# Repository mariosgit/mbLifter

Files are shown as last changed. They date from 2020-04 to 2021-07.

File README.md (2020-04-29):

# mb'Lifter 

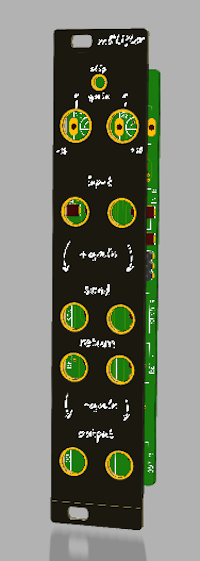
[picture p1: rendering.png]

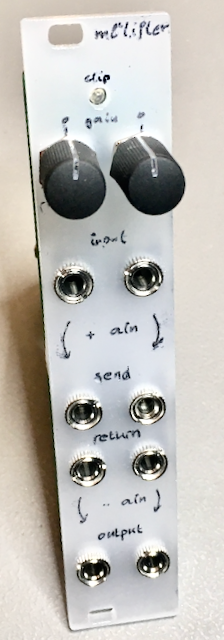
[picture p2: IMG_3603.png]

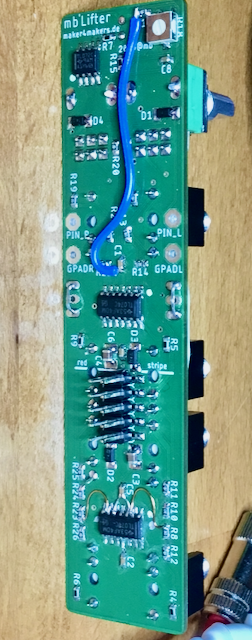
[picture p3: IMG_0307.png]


## What is it

It's a amplifier and attenuator, both coupled and controlled by one knob.

Input -> Amplify -> Attenuate -> Output

or

Input -> Attenuate -> Amplify -> Output.

the middle connection (gained or attenuated signal) can be routed anywhere.

Gain range: -18...+18 dB

It has 2 channels doing this.

Clip indicator - lights up when one of the channels opamps runs into clipping, that is signal level above +-10V peak to peak.

Other features Reverse voltage protection, requires +-12V and needs +-25mA. Width = 5HP = 25mm = almost 1".

### But Why ?

Original idea was to drive an overdrive/distortion unit, so it gains the signal, passes it to the distortion stuff, and then it attenuates to the original levels. In this way the distorted signal does not get louder only distorteder.

### Usecases

* Drive signal into distortion.

### Misuseable as

* InOut - Input an Aux signal (gain Line level to Rack level) AND Output Rack signals with Line level.
* Effect Adapter - Use Guitar effects in your rack - Attenuate to FX(line) level -> FX -> Gain back into Rack Level. Or other way around - use your rack as guitar FX unit.
* Instrument interface - cascade both channels to achive max gain of 36dB, sufficient for Mics and Guitars.
* ...

## Files in repo...

### /pcb

* Lifter01 is the beta version, left here as reference. Had a view minor bugs.
  * Missing feedback caps.
  * 2 wrongly flipped opamp gates.
* Lifter02 - current production version, labeled as "version1.0"
* FrontPCB - as name says.

## License

#### Attribution-NonCommercial-ShareAlike - CC BY-NC-SA 

```
Attribution — You must give appropriate credit, provide a link to the license, and indicate if changes were made. You may do so in any reasonable manner, but not in any way that suggests the licensor endorses you or your use.

NonCommercial — You may not use the material for commercial purposes.

ShareAlike — If you remix, transform, or build upon the material, you must distribute your contributions under the same license as the original.

No additional restrictions — You may not apply legal terms or technological measures that legally restrict others from doing anything the license permits.
```
[All the legal blabla here](https://creativecommons.org/licenses/by-nc-sa/4.0/legalcode)

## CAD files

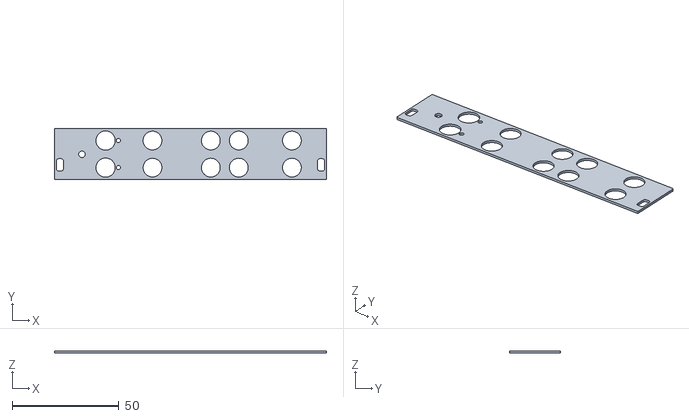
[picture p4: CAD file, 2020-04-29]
Spacer.stl
127.4 x 24.1 x 1.00

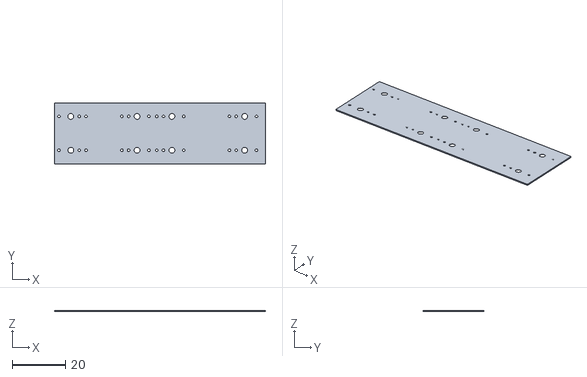
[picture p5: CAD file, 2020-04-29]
Isolator.stl
79.2 x 23.0 x 0.4

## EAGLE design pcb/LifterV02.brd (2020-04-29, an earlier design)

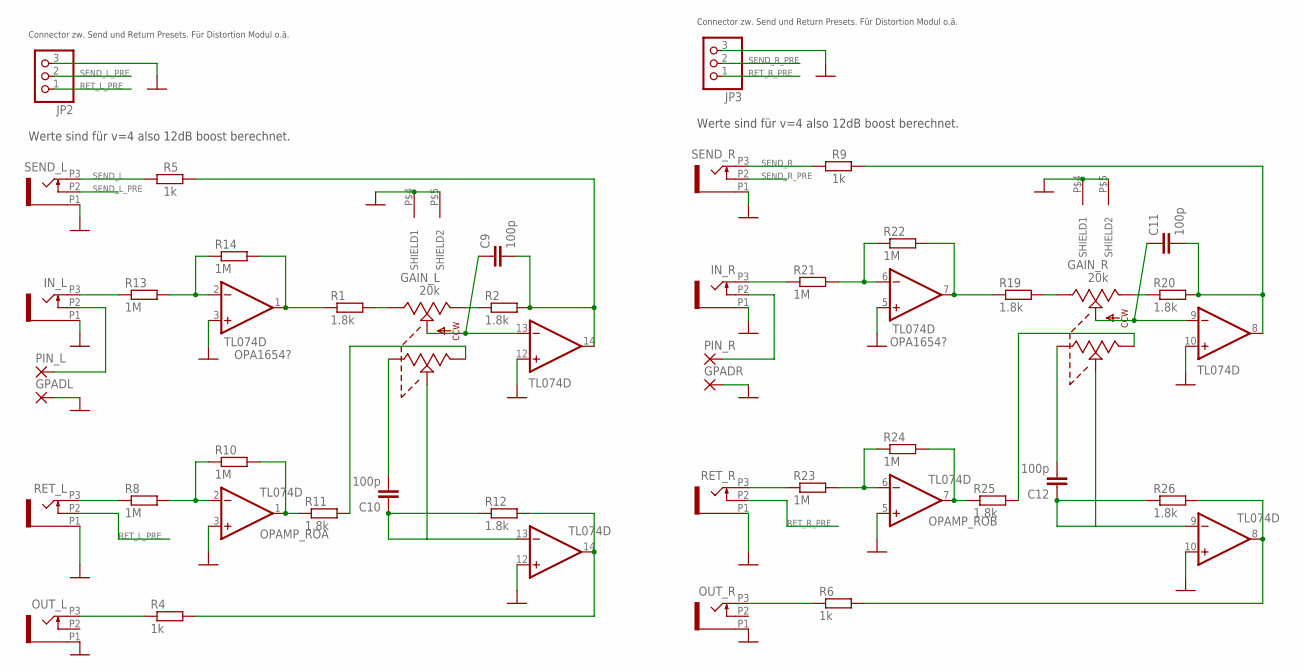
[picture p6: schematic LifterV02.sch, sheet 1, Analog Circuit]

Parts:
C9, C10, C11, C12: 100p; C0603
GAIN_L: 20k; TT_2TAP_VERTICAL
GAIN_R: 20k; TT_2TAP_VERTICAL
GPADL: 3,17/1,3
GPADR: 3,17/1,3
IN_L: PJ301_THONKICONN6; WQP_PJ_301M6
IN_R: PJ301_THONKICONN6; WQP_PJ_301M6
JP2, JP3: PINHD-1X3; 1X03
OPAMP_IS: TL074D; SO14
OPAMP_RO: TL074D; SO14
OUT_L: PJ301_THONKICONN6; WQP_PJ_301M6
OUT_R: PJ301_THONKICONN6; WQP_PJ_301M6
PIN_L: 3,17/1,3
PIN_R: 3,17/1,3
R1, R2, R11, R12, R19, R20, R25, R26: 1.8k; R0603
R4, R5, R6, R9: 1k; R0603
R8, R10, R13, R14, R21, R22, R23, R24: 1M; R0603
RET_L: PJ301_THONKICONN6; WQP_PJ_301M6
RET_R: PJ301_THONKICONN6; WQP_PJ_301M6
SEND_L: PJ301_THONKICONN6; WQP_PJ_301M6
SEND_R: PJ301_THONKICONN6; WQP_PJ_301M6

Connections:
GND: GAIN_L.P$4 (SHIELD1), GAIN_L.P$5 (SHIELD2), GAIN_R.P$4 (SHIELD1), GAIN_R.P$5 (SHIELD2), GPADL.1, GPADR.1, IN_L.P1 (1), IN_R.P1 (1), JP2.3, JP3.3, OPAMP_IS.3 (+IN), OPAMP_IS.5 (+IN), OPAMP_IS.10 (+IN), OPAMP_IS.12 (+IN), OPAMP_RO.3 (+IN), OPAMP_RO.5 (+IN), OPAMP_RO.10 (+IN), OPAMP_RO.12 (+IN), OUT_L.P1 (1), OUT_R.P1 (1), RET_L.P1 (1), RET_R.P1 (1), SEND_L.P1 (1), SEND_R.P1 (1); also elsewhere on the board
unnamed: GAIN_L.CCW, R2.1
unnamed: GAIN_L.CW, R1.2
unnamed: C9.2, OPAMP_IS.14 (OUT), R2.2, R5.2
unnamed: C9.1, GAIN_L.CENTER, OPAMP_IS.13 (-IN)
unnamed: IN_L.P3 (3), R13.1
unnamed: OPAMP_IS.2 (-IN), R13.2, R14.1
unnamed: OPAMP_IS.1 (OUT), R1.1, R14.2
unnamed: OUT_L.P3 (3), R4.1
unnamed: R8.1, RET_L.P3 (3)
unnamed: IN_L.P2 (2), PIN_L.1
unnamed: OPAMP_RO.2 (-IN), R8.2, R10.1
unnamed: C10.2, GAIN_L.CW1
unnamed: C11.2, OPAMP_IS.8 (OUT), R9.2, R20.2
unnamed: OPAMP_RO.1 (OUT), R10.2, R11.1
unnamed: GAIN_L.CCW1, R11.2
unnamed: C10.1, GAIN_L.CENTER1, OPAMP_RO.13 (-IN), R12.1
unnamed: OPAMP_RO.14 (OUT), R4.2, R12.2
unnamed: IN_R.P2 (2), PIN_R.1
unnamed: GAIN_R.CW, R19.2
unnamed: C11.1, GAIN_R.CENTER, OPAMP_IS.9 (-IN)
unnamed: GAIN_R.CCW, R20.1
unnamed: IN_R.P3 (3), R21.1
unnamed: OPAMP_IS.6 (-IN), R21.2, R22.1
unnamed: OPAMP_IS.7 (OUT), R19.1, R22.2
unnamed: R23.1, RET_R.P3 (3)
unnamed: OPAMP_RO.6 (-IN), R23.2, R24.1
unnamed: OPAMP_RO.7 (OUT), R24.2, R25.1
unnamed: GAIN_R.CCW1, R25.2
unnamed: C12.2, GAIN_R.CW1
unnamed: C12.1, GAIN_R.CENTER1, OPAMP_RO.9 (-IN), R26.1
unnamed: OPAMP_RO.8 (OUT), R6.2, R26.2
unnamed: OUT_R.P3 (3), R6.1
RET_L_PRE: JP2.1, RET_L.P2 (2)
RET_R_PRE: JP3.1, RET_R.P2 (2)
SEND_L: R5.1, SEND_L.P3 (3); also elsewhere on the board
SEND_L_PRE: JP2.2, SEND_L.P2 (2)
SEND_R: R9.1, SEND_R.P3 (3); also elsewhere on the board
SEND_R_PRE: JP3.2, SEND_R.P2 (2)

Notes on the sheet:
OPA1654?
Connector zw. Send und Return Presets. Für Distortion Modul o.ä.
Werte sind für v=4 also 12dB boost berechnet.

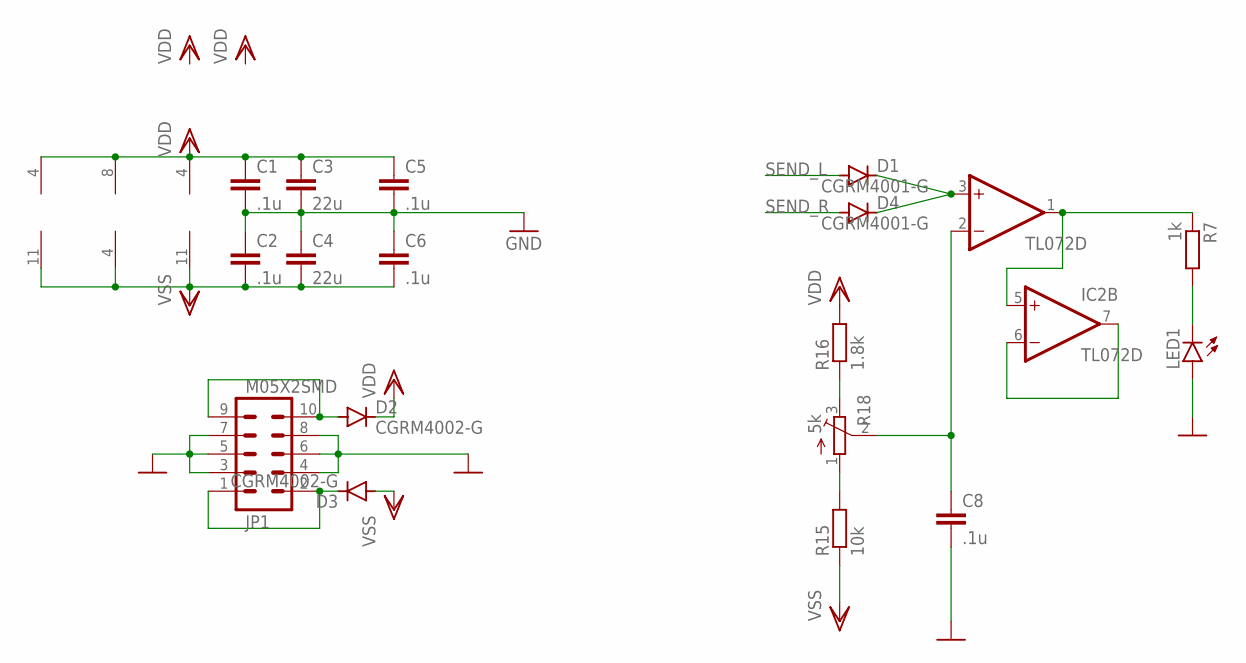
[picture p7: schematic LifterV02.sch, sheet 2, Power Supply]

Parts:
C1, C2, C5, C6, C8: .1u; C0603
C3, C4: 22u; C1210
D1, D4: CGRM4001-G; SOD-123_MINI-SMA
D2, D3: CGRM4002-G; SOD-123_MINI-SMA
IC2: TL072D; SO08
JP1: M05X2SMD; 2X5-SMD
LED1: LED3MM
OPAMP_IS: TL074D; SO14
OPAMP_RO: TL074D; SO14
R7: 1k; R0603
R15: 10k; R0603
R16: 1.8k; R0603
R18: 5k; 3223G; MOUSER 652-TC33X-2-502G

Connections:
GND: C1.2, C2.1, C3.2, C4.1, C5.2, C6.1, C8.2, JP1.3, JP1.4, JP1.5, JP1.6, JP1.7, JP1.8, LED1.A; also elsewhere on the board
unnamed: IC2.6 (-IN), IC2.7 (OUT)
unnamed: D2.A, JP1.9, JP1.10
unnamed: D1.C, D4.C, IC2.3 (+IN)
unnamed: D3.C, JP1.1, JP1.2
unnamed: LED1.K (C), R7.2
unnamed: IC2.1 (OUT), IC2.5 (+IN), R7.1
unnamed: C8.1, IC2.2 (-IN), R18.2 (S)
unnamed: R16.1, R18.3 (E)
unnamed: R15.2, R18.1 (A)
SEND_L: D1.A; also elsewhere on the board
SEND_R: D4.A; also elsewhere on the board
VDD: C1.1, C3.1, C5.1, D2.C, IC2.8 (V+), OPAMP_IS.4 (V+), OPAMP_RO.4 (V+), R16.2
VSS: C2.2, C4.2, C6.2, D3.A, IC2.4 (V-), OPAMP_IS.11 (V-), OPAMP_RO.11 (V-), R15.1

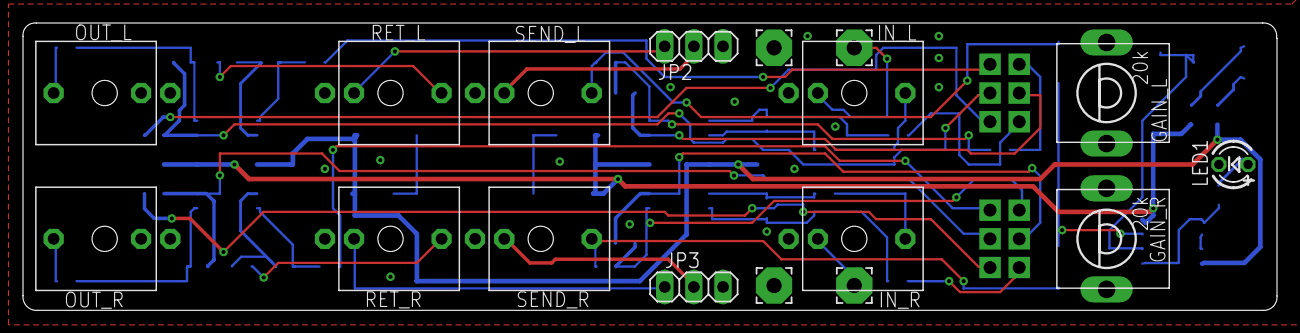
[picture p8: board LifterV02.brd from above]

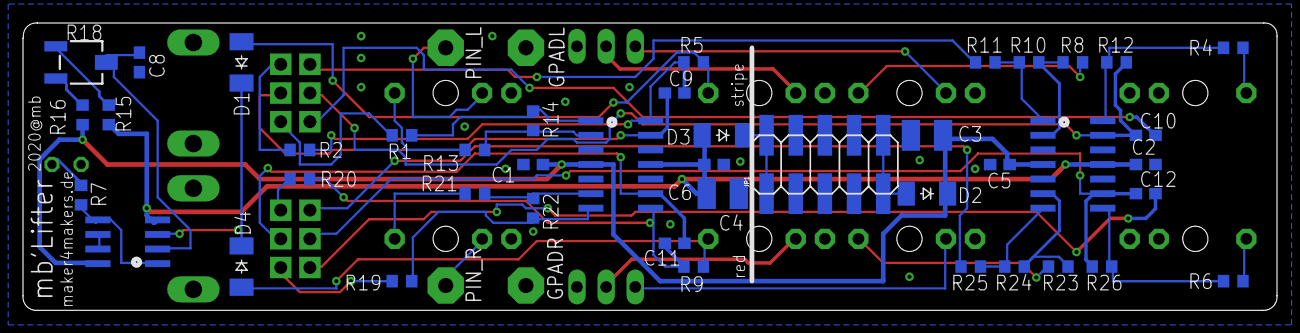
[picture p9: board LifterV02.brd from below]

Board: 2 copper layers, 109.2 x 25.0 mm, 60 parts (43 on the bottom side), 50 nets.

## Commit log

2020-04-05 more images
    [LifterV02.brd]
2020-04-28 increased pot drill 9mm/355mil
    [FrontPCB.brd]
2020-04-29 Minor changes to pcb text, Added Spacer and Isolator, Added License
    [Isolator.stl, Spacer.stl]
2021-06-02 added a simulation file
    [opamp1.sch]
2021-06-02 added diode distortion sim
    [opamp1.sch]
2021-07-12 BigMac changes.
    [FrontPCB.brd, LifterV02.brd, LifterV03.brd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]
